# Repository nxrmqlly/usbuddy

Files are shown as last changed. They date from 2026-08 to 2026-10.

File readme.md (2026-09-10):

# usbuddy

A cute USB buddy. The PCB plugs straight into your laptop and can show messages based on serial input.
Powered by the `CH552G`, a generic `0.91" 128x32 SSD1305`, and a `WS2812B-2020` Neopixel.

## PCB

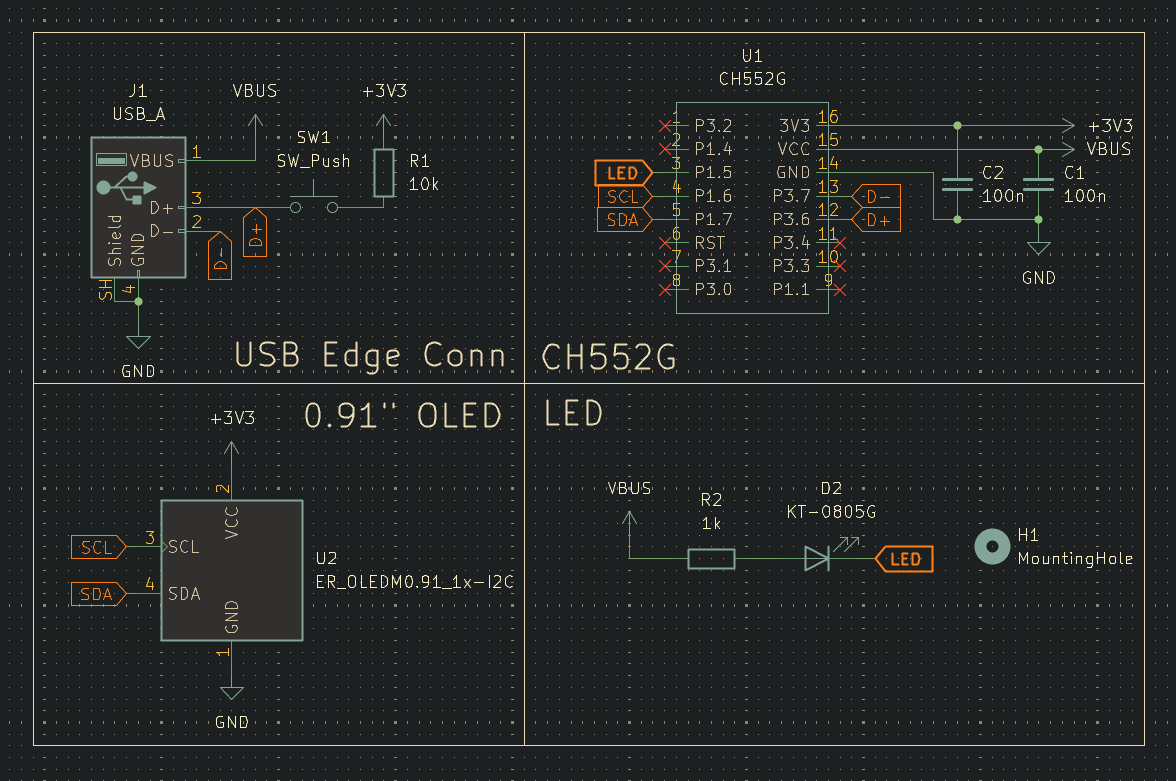
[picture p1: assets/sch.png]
schematic

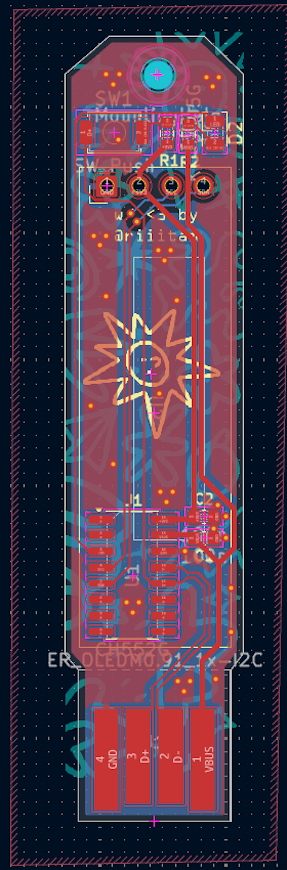
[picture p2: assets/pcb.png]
pcb routing

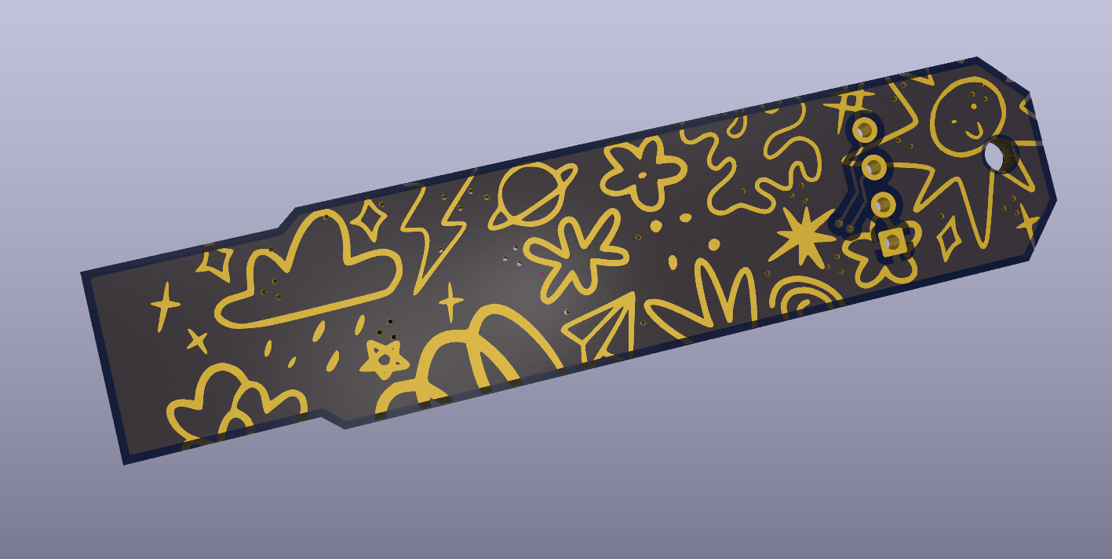
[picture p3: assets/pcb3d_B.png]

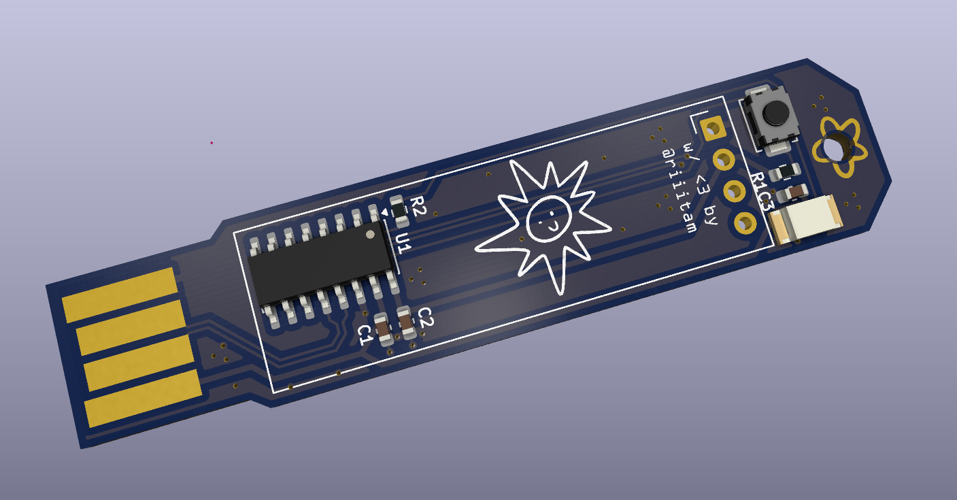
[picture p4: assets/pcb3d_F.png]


## CAD

### [OnShape Link](https://cad.onshape.com/documents/ad3ec215ff10d03571851e1e/w/97fc9671f557026641b18237/e/4b67f7499092e09124438d32)

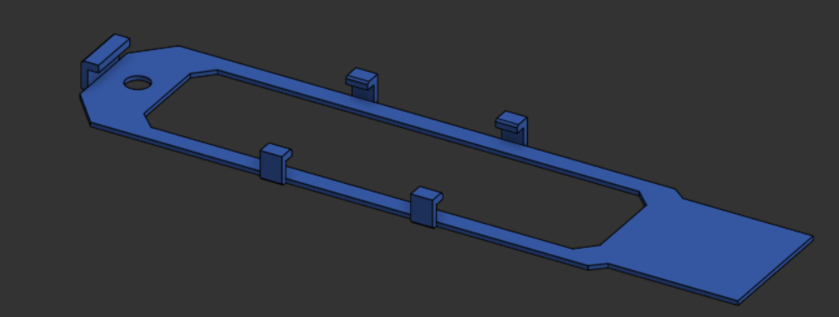
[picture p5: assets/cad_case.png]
cad case

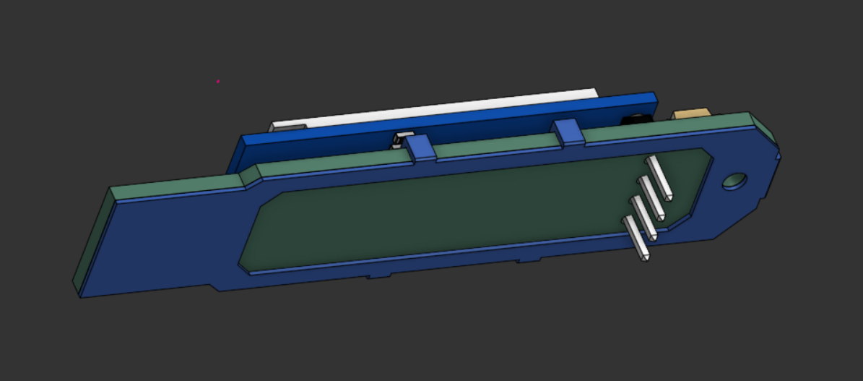
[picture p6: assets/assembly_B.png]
cad assembly back

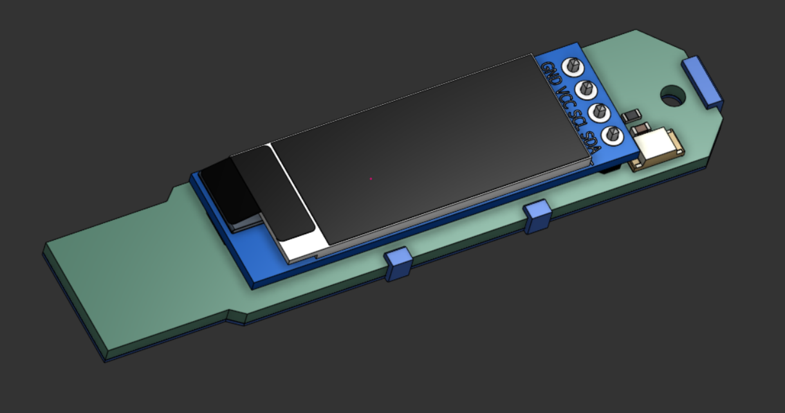
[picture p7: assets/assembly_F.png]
cad assembly front

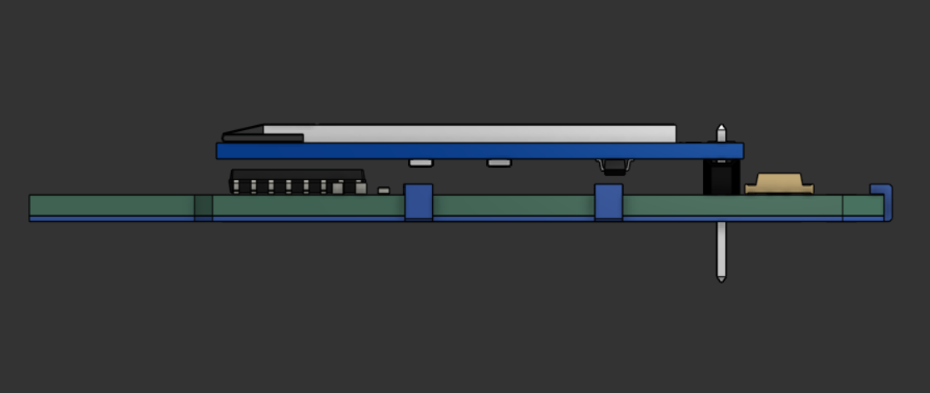
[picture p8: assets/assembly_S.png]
cad assembly side


## BOM

| Designator | Footprint | Quantity | Value | LCSC Part # | Cost (1u) |
| --- | --- | --- | --- | --- | --- |
| C1, C2 | 0603 | 2 | 100n | C14663 | $0.04 |
| D2 | 0805 | 1 | KT-0805G | C2297 | $0.02 |
| J1 | USB-A | 1 | USB_A | | |
| R1 | 0603 | 1 | 10k | C25804 | $0.01 |
| R2 | 0603 | 1 | 1k | C21190 | $0.01 |
| SW1 | SW_SPST_TS-1088-xR020 | 1 | SW_Push | C720477 | $0.05 |
| U1 | SOIC-16_3.9x9.9mm_P1.27mm  | 1 | CH552G | C111292 | $0.74 |
| U2 | ER_OLEDM0.91_1x-I2C_NoCtyd | 1 | ER_OLEDM0.91_1x-I2C | | $1.20 |

## Cost of Production

| Option | Qty | PCB Fabrication | PCBA & Parts | OLED + LED | Shipping |  **Total** |
| --- | --: | ---: | ---: | ---: | ---: | ---: |
| **5 assembled (ENIG)** | 5 | $20.62 | $18.03 | $6.00 | $9.92 | **$54.57** |
| **5 assembled (HASL)** | 5 | $4.00 | $18.03 | $6.00 | $9.92 | **$39.95** |

### Discounts (not accounted in total)

- -$2.00 JLCONE App
- -$9.00 PCBA Coupon

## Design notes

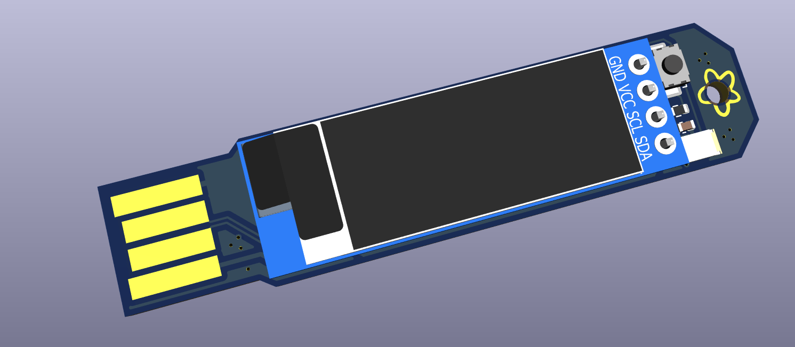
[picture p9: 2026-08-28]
assets/pcb3d_withscreen.png

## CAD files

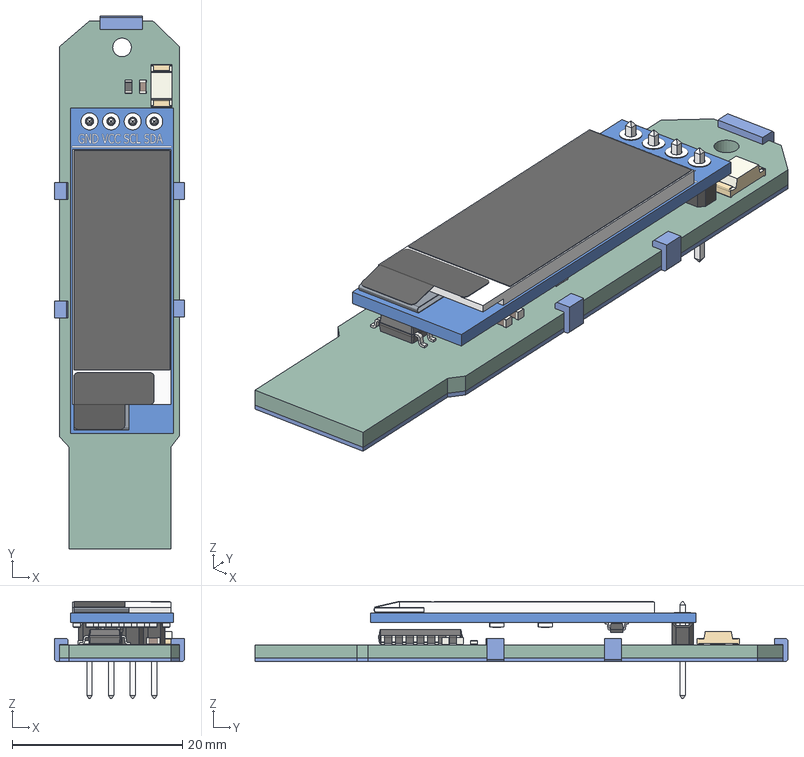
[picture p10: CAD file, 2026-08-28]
hardware/cad/usbuddy-assembly.step
15.3 x 62.7 x 11.5 mm
RESC-0603_2 x 3
R_0603_1608Metric_1
RESC-0603_10 x 3
Pin Header 4 x 1 TH 2.54mm Pitch x 8
RESC-0603 x 3
RESC-0603_5 x 3
RESC-0603_8 x 3
LED_2010_5025Metric
C_0603_1608Metric_2
RESC-0603_11 x 3
RESC-0603_4 x 3
RESC-0603_1 x 3
RESC-0603_9 x 3
OLED_0.91_128x32
RESC-0603_3 x 3
RESC-0603_12 x 3
2SD0601A x 4
usbuddy_PCB
RESC-0603_7 x 3
RESC-0603_6 x 3
R_0603_1608Metric
C_0603_1608Metric
SOIC-16_3.9x9.9mm_P1.27mm
C_0603_1608Metric_1

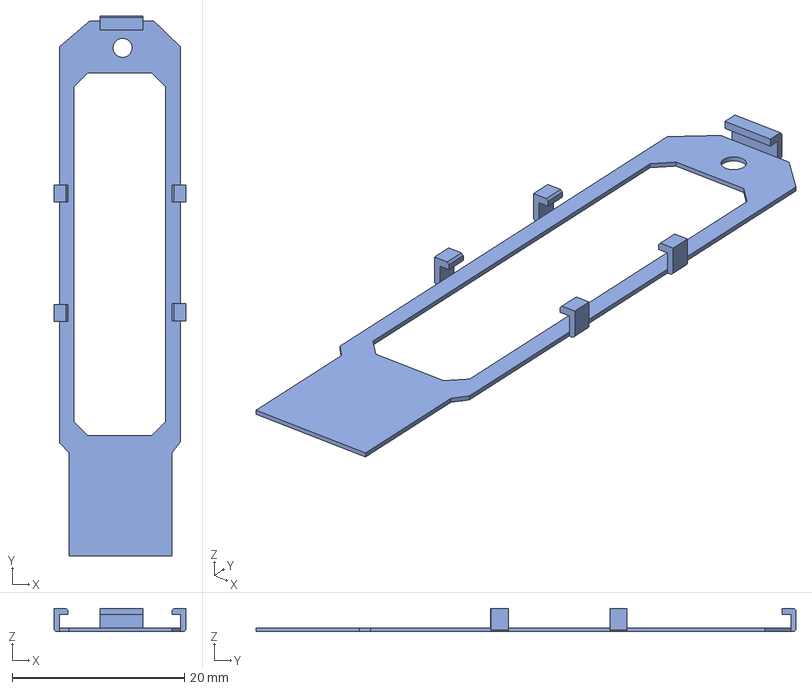
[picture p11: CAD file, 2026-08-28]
hardware/cad/usbuddy-case.step
15.3 x 62.7 x 2.70 mm

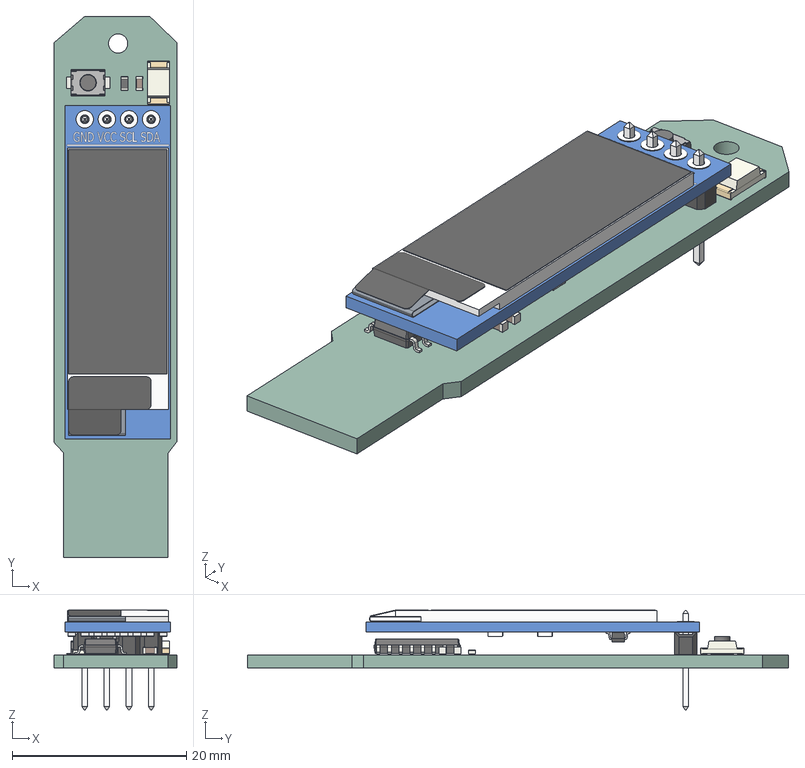
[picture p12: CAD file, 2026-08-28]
hardware/cad/pcb.step
14.1 x 62.1 x 11.5 mm
C_0603_1608Metric x 3
OLED_0.91_128x32
Pin Header 4 x 1 TH 2.54mm Pitch
RESC-0603 x 13
2SD0601A
R_0603_1608Metric x 2
SW_SPST_TS-1088-xR020
SOIC-16_3.9x9.9mm_P1.27mm
LED_2010_5025Metric
usbuddy_PCB

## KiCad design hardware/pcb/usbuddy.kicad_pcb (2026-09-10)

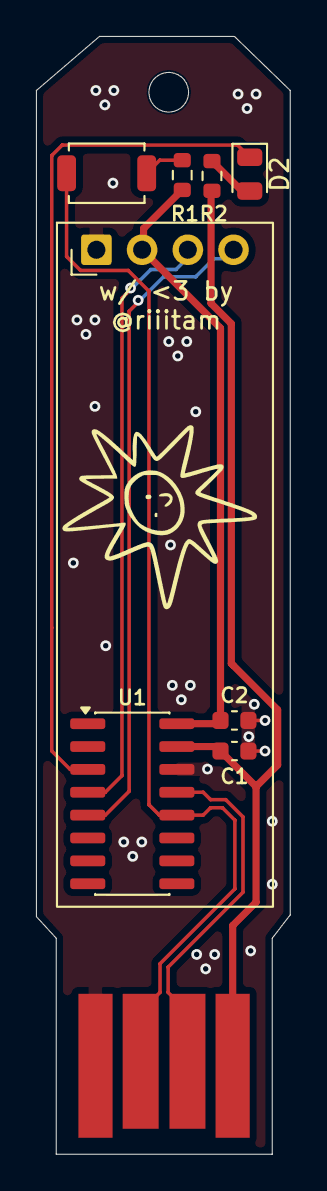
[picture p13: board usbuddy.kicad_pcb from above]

Board: 2 copper layers, 14.1 x 62.1 mm, 10 parts (0 on the bottom side), 10 nets.

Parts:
C1, C2: 100n; C_0603_1608Metric
D2: KT-0805G; LED_0805_2012Metric
H1: MountingHole; MountingHole_2.2mm_M2
J1: USB_A; USB-A
R1: 10k; R_0603_1608Metric
R2: 1k; R_0603_1608Metric
SW1: SW_Push; SW_SPST_TS-1088-xR020
U1: CH552G; SOIC-16_3.9x9.9mm_P1.27mm
U2: ER_OLEDM0.91_1x-I2C; ER_OLEDM0.91_1x-I2C_NoCtyd

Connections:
+3V3: C2.1, R1.1, U1.16 (3V3), U2.2 (VCC)
D+: J1.3 (D+), SW1.1, U1.12 (P3.6)
D-: J1.2 (D-), U1.13 (P3.7)
GND: C1.2, C2.2, J1.4 (GND), U1.14 (GND), U2.1 (GND)
LED: D2.1 (K), U1.3 (P1.5)
unnamed: D2.2 (A), R2.2
unnamed: R1.2, SW1.2
SCL: U1.4 (P1.6), U2.3 (SCL)
SDA: U1.5 (P1.7), U2.4 (SDA)
VBUS: C1.1, J1.1 (VBUS), R2.1, U1.15 (VCC)

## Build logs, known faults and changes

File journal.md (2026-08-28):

# usbuddy

A cute usb device that plugs straight into your laptop and talks to the laptop via usb serial.
You can show any messages you want

_Total Hours: 3 + 4 + 7 = 14h_

# 27-08-2026 Night: Getting started

_Time: 3h_

## Schematic

I decided to use:

- CH552G for MCU
- Generic 0.91" OLED (SSD1305)
- A Worldsemi WS2812B-2020 Neopixel

Since the project is so simple, the schematic wasn't hard but I learnt that SCL/SDA on I2C for the
OLED requires Pull Ups, so I had added that but thanks to #electronics, I learnt that the module I
am using probably comes with the pull ups on the board, so thats nice.

Though the WS2812B-2020 has a internal filter cap, I dont exactly need a 100n cap next to it on the
VBUS line but having it is no harm so im keeping it there. I can always DNP it IRL.

## Routing

The shape was simple too, its just a long boi due to the screen, with an edge connector and on the
other side, a button and a neopixel. Also added a mounting hole to the assembly.

# 28-08-2026 Midnight: CAD and Art

_Time: 4h_

## CAD

I don't like cad, and cad doesn't like me. I tried to import the dxf from kicad but it was all in
vain. Well then I tried importing the STEP of the board into kicad and base my part after it, and it
worked!

The problem was realized a lot later when I went to remove the pcb from the part, i couldnt delete it
because my entire work was based on that... there was no way to isolate the body....

So then I did the most genius thing... I redid the CAD, this time using the same importing STEP trick
but I deleted the rest of the faces except the bottom face, and then based my 3d model based off it.

cad model picture

## Artwork

I found some free doodles on Figma, and I combined a bunch of them into this cool mosiac thing.
I really love the sun!

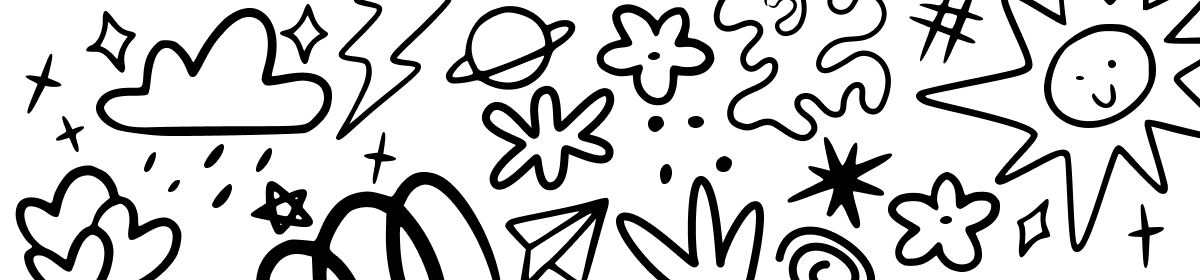
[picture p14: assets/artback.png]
pcb art


Next, I imported these into KiCad using the inbuilt image converter and put it on the F.Mask layer!
Doing that allows me to expose the copper (W ENIG!) underneath and instead of white silkscreen we get
gold colored art!

pcb art on pcb

# 28-08-2026 Morning: CAD and Art

_Time: 7h_

I got an extension! yay!

## Bugs

I realised that I had wired the pins on the OLED wrong, so I just got myself a special symbol from the
internet for this) this gave me a nice footprint and symbol to work with instead of juggling conn pins on the
board. Also I modified the footprint to remove the courtyard so it wont complain in the PCB editor

For safety and reducing ringing I added a 470ohm resistor in series to the neopixel line (b/w gpio and DIN)

## Firmware

The CH552G has 1 kb of RAM, 148 bytes is used for the usb stack.

So to run a full buffered OLED, I need to have 128*32/8 = 512 bytes in memory, but I simply dont have enough
RAM on the chip. So, I am gonna use the oled in unbuffered mode, less capability but uses essentially zero bytes
of RAM. It just injects a u8x8 pixels straight into the oled.

## Finishing up

I made the cad assembly (just one part and the exported step from KiCad) and wrote a bit of journals and took a few
screenshots, DONE!

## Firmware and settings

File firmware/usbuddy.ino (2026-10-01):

/*
 * usbuddy
 * -------
 *
 * CH552G + SSD1306 128x32
 *
 *   P3.7 : D-
 *   P3.6 : D+
 *   P1.6 : SCL
 *   P1.7 : SDA
 *   P1.5 : LED  : active low

 * Commands:
 *   TEXT:hello      -> clears the screen, prints on line 0
 *   LINE1:hello     -> prints on line 1 (also LINE2:, LINE3:)
 *   CLEAR           -> clear screen
 *   LED:255         -> set LED brightness
 */

#include <stdlib.h>
#include <string.h>

#define LED_PIN  15
#define LED_ON   LOW    // active low
#define LED_OFF  HIGH

#define SCL_PIN  16
#define SDA_PIN  17

// 1 to flip
#define H_FLIP 0
#define V_FLIP 0

#define OLED_ADDR  0x78   // 0x3C << 1
#define OLED_COLS  128
#define OLED_PAGES 4      // 32 px / 8
#define CHAR_W     6      // 5 px glyph + 1 px gap
#define LINE_CHARS 21     // 128 / 6

static const uint8_t __code font5x7[] = {
  0x00,0x00,0x00,0x00,0x00, // ' '
  0x00,0x00,0x5F,0x00,0x00, // !
  0x00,0x07,0x00,0x07,0x00, // "
  0x14,0x7F,0x14,0x7F,0x14, // #
  0x24,0x2A,0x7F,0x2A,0x12, // $
  0x23,0x13,0x08,0x64,0x62, // %
  0x36,0x49,0x55,0x22,0x50, // &
  0x00,0x05,0x03,0x00,0x00, // '
  0x00,0x1C,0x22,0x41,0x00, // (
  0x00,0x41,0x22,0x1C,0x00, // )
  0x14,0x08,0x3E,0x08,0x14, // *
  0x08,0x08,0x3E,0x08,0x08, // +
  0x00,0x50,0x30,0x00,0x00, // ,
  0x08,0x08,0x08,0x08,0x08, // -
  0x00,0x60,0x60,0x00,0x00, // .
  0x20,0x10,0x08,0x04,0x02, // /
  0x3E,0x51,0x49,0x45,0x3E, // 0
  0x00,0x42,0x7F,0x40,0x00, // 1
  0x42,0x61,0x51,0x49,0x46, // 2
  0x21,0x41,0x45,0x4B,0x31, // 3
  0x18,0x14,0x12,0x7F,0x10, // 4
  0x27,0x45,0x45,0x45,0x39, // 5
  0x3C,0x4A,0x49,0x49,0x30, // 6
  0x01,0x71,0x09,0x05,0x03, // 7
  0x36,0x49,0x49,0x49,0x36, // 8
  0x06,0x49,0x49,0x29,0x1E, // 9
  0x00,0x36,0x36,0x00,0x00, // :
  0x00,0x56,0x36,0x00,0x00, // ;
  0x08,0x14,0x22,0x41,0x00, // <
  0x14,0x14,0x14,0x14,0x14, // =
  0x00,0x41,0x22,0x14,0x08, // >
  0x02,0x01,0x51,0x09,0x06, // ?
  0x32,0x49,0x79,0x41,0x3E, // @
  0x7E,0x11,0x11,0x11,0x7E, // A
  0x7F,0x49,0x49,0x49,0x36, // B
  0x3E,0x41,0x41,0x41,0x22, // C
  0x7F,0x41,0x41,0x22,0x1C, // D
  0x7F,0x49,0x49,0x49,0x41, // E
  0x7F,0x09,0x09,0x09,0x01, // F
  0x3E,0x41,0x49,0x49,0x7A, // G
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
  0x02,0x04,0x08,0x10,0x20, // backslash
  0x00,0x41,0x41,0x7F,0x00, // ]
  0x04,0x02,0x01,0x02,0x04, // ^
  0x40,0x40,0x40,0x40,0x40, // _
  0x00,0x01,0x02,0x04,0x00, // `
  0x20,0x54,0x54,0x54,0x78, // a
  0x7F,0x48,0x44,0x44,0x38, // b
  0x38,0x44,0x44,0x44,0x20, // c
  0x38,0x44,0x44,0x48,0x7F, // d
  0x38,0x54,0x54,0x54,0x18, // e
  0x08,0x7E,0x09,0x01,0x02, // f
  0x0C,0x52,0x52,0x52,0x3E, // g
  0x7F,0x08,0x04,0x04,0x78, // h
  0x00,0x44,0x7D,0x40,0x00, // i
  0x20,0x40,0x44,0x3D,0x00, // j
  0x7F,0x10,0x28,0x44,0x00, // k
  0x00,0x41,0x7F,0x40,0x00, // l
  0x7C,0x04,0x18,0x04,0x78, // m
  0x7C,0x08,0x04,0x04,0x78, // n
  0x38,0x44,0x44,0x44,0x38, // o
  0x7C,0x14,0x14,0x14,0x08, // p
  0x08,0x14,0x14,0x18,0x7C, // q
  0x7C,0x08,0x04,0x04,0x08, // r
  0x48,0x54,0x54,0x54,0x20, // s
  0x04,0x3F,0x44,0x40,0x20, // t
  0x3C,0x40,0x40,0x20,0x7C, // u
  0x1C,0x20,0x40,0x20,0x1C, // v
  0x3C,0x40,0x30,0x40,0x3C, // w
  0x44,0x28,0x10,0x28,0x44, // x
  0x0C,0x50,0x50,0x50,0x3C, // y
  0x44,0x64,0x54,0x4C,0x44, // z
  0x00,0x08,0x36,0x41,0x00, // {
  0x00,0x00,0x7F,0x00,0x00, // |
  0x00,0x41,0x36,0x08,0x00, // }
  0x08,0x04,0x08,0x10,0x08  // ~
};

/* ---------------- bit banged I2C (w/o, no r) ----------------
 * never reads back, and the ACK clock is just ignored.        */

static void i2cStart(void) {
  digitalWrite(SDA_PIN, HIGH);
  digitalWrite(SCL_PIN, HIGH);
  digitalWrite(SDA_PIN, LOW);
  digitalWrite(SCL_PIN, LOW);
}

static void i2cStop(void) {
  digitalWrite(SDA_PIN, LOW);
  digitalWrite(SCL_PIN, HIGH);
  digitalWrite(SDA_PIN, HIGH);
}

static void i2cWrite(uint8_t b) {
  uint8_t i;
  for (i = 0; i < 8; i++) {
    digitalWrite(SDA_PIN, (b & 0x80) ? HIGH : LOW);
    digitalWrite(SCL_PIN, HIGH);
    digitalWrite(SCL_PIN, LOW);
    b <<= 1;
  }
  // 9th clock ack ignored
  digitalWrite(SDA_PIN, HIGH);
  digitalWrite(SCL_PIN, HIGH);
  digitalWrite(SCL_PIN, LOW);
}

/* ---------------- SSD1306 ---------------- */

static void oledCmd(uint8_t c) {
  i2cStart();
  i2cWrite(OLED_ADDR);
  i2cWrite(0x00);        // control byte: command
  i2cWrite(c);
  i2cStop();
}

static void oledSetPos(uint8_t page, uint8_t col) {
  oledCmd(0xB0 | (page & 0x07));
  oledCmd(0x00 | (col & 0x0F));
  oledCmd(0x10 | (col >> 4));
}

static void oledClear(void) {
  uint8_t p, c;
  for (p = 0; p < OLED_PAGES; p++) {
    oledSetPos(p, 0);
    i2cStart();
    i2cWrite(OLED_ADDR);
    i2cWrite(0x40);           // control byte: data
    for (c = 0; c < OLED_COLS; c++) i2cWrite(0x00);
    i2cStop();
  }
}

static void oledSetFlip(uint8_t h, uint8_t v) {
  oledCmd(h ? 0xA0 : 0xA1);   // segment remap  (horizontal flip)
  oledCmd(v ? 0xC0 : 0xC8);   // COM scan dir   (vertical flip)
}

static void oledInit(void) {
  pinMode(SCL_PIN, OUTPUT);
  pinMode(SDA_PIN, OUTPUT);
  digitalWrite(SCL_PIN, HIGH);
  digitalWrite(SDA_PIN, HIGH);
  delay(100);                            // let the display power up

  oledCmd(0xAE);                         // display off
  oledCmd(0xD5); oledCmd(0x80);          // clock divide
  oledCmd(0xA8); oledCmd(0x1F);          // multiplex = 32 rows
  oledCmd(0xD3); oledCmd(0x00);          // display offset 0
  oledCmd(0x40);                         // start line 0
  oledCmd(0x8D); oledCmd(0x14);          // charge pump on
  oledCmd(0x20); oledCmd(0x02);          // page addressing mode
  oledSetFlip(H_FLIP, V_FLIP);           // orientation
  oledCmd(0xDA); oledCmd(0x02);          // COM pins (128x32)
  oledCmd(0x81); oledCmd(0x8F);          // contrast
  oledCmd(0xD9); oledCmd(0xF1);          // precharge
  oledCmd(0xDB); oledCmd(0x40);          // VCOMH
  oledCmd(0xA4);                         // follow RAM
  oledCmd(0xA6);                         // normal (not inverted)
  oledCmd(0xAF);                         // display on

  oledClear();
}

// draw a string on a text line (0..3); anything past 21 chars is cut off
static void oledPrint(uint8_t line, const char *s) {
  uint8_t n = 0, i;
  uint16_t base;
  char c;

  if (line >= OLED_PAGES) return;
  oledSetPos(line, 0);

  i2cStart();
  i2cWrite(OLED_ADDR);
  i2cWrite(0x40);
  while (*s && n < LINE_CHARS) {
    c = *s++;
    if (c < 32 || c > 126) c = '?';
    base = (uint16_t)(c - 32) * 5;
    for (i = 0; i < 5; i++) i2cWrite(font5x7[base + i]);
    i2cWrite(0x00);      // gap column
    n++;
  }
  i2cStop();
}

/* ---------------- serial cmd handling ---------------- */

// Parse "r,g,b" (or just one number)
static uint8_t parseMaxValue(const char *p) {
  uint8_t best = 0, count = 0;
  uint16_t n;
  while (*p && count < 3) {
    while (*p == ' ') p++;
    n = 0;
    while (*p >= '0' && *p <= '9') {
      n = n * 10 + (*p - '0');
      if (n > 255) n = 255;
      p++;
    }
    if ((uint8_t)n > best) best = (uint8_t)n;
    count++;
    while (*p && *p != ',') p++;   // skip to next value
    if (*p == ',') p++;
  }
  return best;
}

static void sendStr(const char *s) {
  while (*s) USBSerial_write(*s++);
}

static void sendU8(uint8_t n) {
  if (n >= 100) USBSerial_write('0' + n / 100);
  if (n >= 10)  USBSerial_write('0' + (n / 10) % 10);
  USBSerial_write('0' + n % 10);
}

static char lineBuf[40];
static uint8_t lineIdx = 0;
static uint8_t ledDuty = 0;    // 0..255 brightness
static uint8_t ledPhase = 0;   // software PWM counter
static uint8_t hFlip = H_FLIP;
static uint8_t vFlip = V_FLIP;

static void handleCommand(char *cmd) {
  if (strncmp(cmd, "HFLIP:", 6) == 0) {
    hFlip = (cmd[6] == '1');
    oledSetFlip(hFlip, vFlip);
    oledClear();   // segment remap only affects newly written data

  } else if (strncmp(cmd, "VFLIP:", 6) == 0) {
    vFlip = (cmd[6] == '1');
    oledSetFlip(hFlip, vFlip);
    oledClear();

  } else if (strncmp(cmd, "TEXT:", 5) == 0) {
    oledClear();
    oledPrint(0, cmd + 5);

  } else if (strncmp(cmd, "LINE", 4) == 0 && cmd[4] >= '0' && cmd[4] <= '3' && cmd[5] == ':') {
    oledPrint(cmd[4] - '0', cmd + 6);

  } else if (strcmp(cmd, "CLEAR") == 0) {
    oledClear();
    sendStr("Cleared Screen");

  } else if (strncmp(cmd, "LED:", 4) == 0) {
    ledDuty = parseMaxValue(cmd + 4);   // loop() does the PWM
    sendStr("LED=");
    sendU8(ledDuty);
    sendStr("\n");
  }
}

void setup() {
  pinMode(LED_PIN, OUTPUT);
  digitalWrite(LED_PIN, LED_OFF);

  oledInit();
  oledPrint(0, "^^^^^^^ hallo ^^^^^^^");
  oledPrint(1, "cmds: TEXT:, LED:,   ");
  oledPrint(2, "      LINE1/2/3:,    ");
  oledPrint(3, "      CLEAR          ");
}

void loop() {
  // bitbang: software pwm: 64 steps per cycle
  ledPhase += 4;
  digitalWrite(LED_PIN, (ledPhase < ledDuty) ? LED_ON : LED_OFF);

  while (USBSerial_available()) {
    char c = USBSerial_read();
    if (c == '\n' || c == '\r' || lineIdx >= sizeof(lineBuf) - 1) {
      if (lineIdx > 0) {
        lineBuf[lineIdx] = '\0';
        lineIdx = 0;
        handleCommand(lineBuf);
      }
    } else {
      lineBuf[lineIdx++] = c;
    }
  }
}

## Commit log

2026-08-28 add project files
    [pcb.step, usbuddy-assembly.step, usbuddy-case.step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]
2026-09-10 update design to use green static LED
    [usbuddy.kicad_pcb, usbuddy.kicad_sch]
2026-09-10 update cost
    [usbuddy.kicad_pcb]
2026-10-01 fix LED brightness setting
    [usbuddy.ino]
